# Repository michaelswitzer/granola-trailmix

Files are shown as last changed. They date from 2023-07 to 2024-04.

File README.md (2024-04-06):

# TrailMix by Granola Arcade

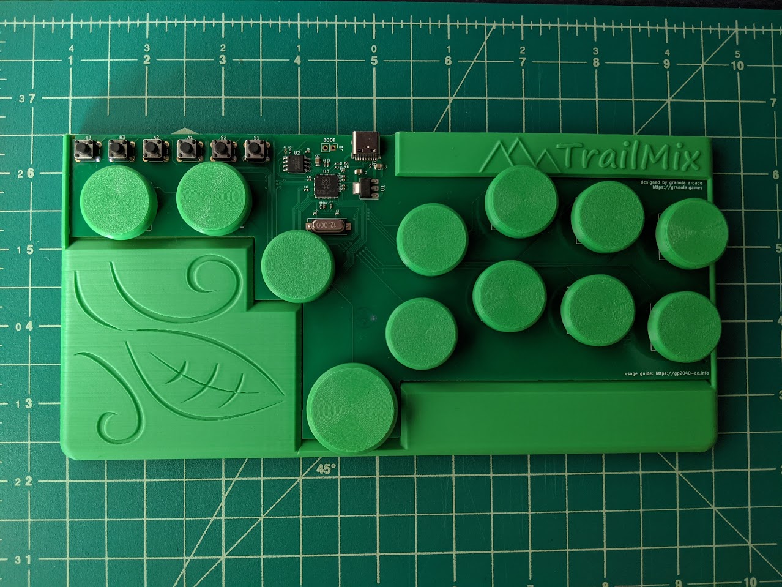
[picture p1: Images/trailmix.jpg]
TrailMix fightstick


The TrailMix is a button box style arcade controller by Granola Arcade. It is designed to provide the minimum cost professional grade arcade stick available. The design of the TrailMix is simplified down to the core, without any of the bells and whistles that add cost and complexity. Win your local without breaking the bank!

You can no longer buy the TrailMix from Granola but you can buy our current controllers at https://granola.games

## Should you make a TrailMix?
Building your own TrailMix will definitely be more expensive than buying one directly from Granola Arcade, and it isn't as fun to put together as some of the other DIY options out there. Nevertheless, if you decide to press on, the files in this repository should have everything you need.

## How to build
To build your own TrailMix, import the PCB designs and bill of materials using KiCAD. I provided a list of parts that use JLCPCB's part assembly services, since that is the company I use to manufacture the PCB. You can use these files as a starting point for building your own PCB.

The STL file for the case is optimized for FDM 3D printers. I recommend PLA with at least 15% infill but you can use any material you wish. The case is designed to be printed on the thin edge on the top side, which can cause some stability challenges when printing. **This orientation is better suited to printers that do not move their print bed side to side, and can be tricky to print on Prusa/Ender/etc. printers.** If you use a "bed slinger" printer such as these, make sure you have good bed adhesion.

You will also need to source your own key switches and keycaps. The TrailMix uses Kailh low-profile "Choc v1" keyboard switches.

## Firmware
The TrailMix is designed to use the <a rel="GP2040-CE firmware" href="https://github.com/OpenStickCommunity/GP2040-CE">GP2040-CE firmware</a>. You want the .uf2 file for the Raspberry Pi Pico as it has the same pinouts as the TrailMix. If you wish to use different firmware, you can view the schematic files to understand the layout of the board. If you bridge the Boot and GND pins (marked "BOOT" on the PCB) as you plug in the USB cord, you can upload new firmware in .uf2 format.

## Credits
The TrailMix was designed by Michael Switzer. The GP2040-CE firmware is maintained by <a href="https://github.com/OpenStickCommunity">OpenStickCommunity</a>. This project was inspired by the <a href="https://github.com/jfedor2/flatbox">Flatbox</a>.

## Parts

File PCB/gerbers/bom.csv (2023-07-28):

Comment | Designator | Footprint | LCSC Part Number
10uF | C1,C2 | Capacitor_SMD:C_0805_2012Metric | C83061
27p | C3,C4 | Capacitor_SMD:C_0402_1005Metric | C147436
100nF | C5,C6,C7,C9,C11,C12,C13,C14,C15,C16 | Capacitor_SMD:C_0402_1005Metric | C115671
1uF | C8,C10 | Capacitor_SMD:C_0402_1005Metric | C5137485
10uF | C17 | Capacitor_SMD:C_0805_2012Metric | C83061
HRO-TYPE-C-31-M-12 | USB1 | Type-C:HRO-TYPE-C-31-M-12-Assembly | C165948
1k | R1,R5 | Capacitor_SMD:C_0402_1005Metric | C105637
5.1k | R6,R7 | Resistor_SMD:R_0402_1005Metric | C25905
27 ohm | R3,R4 | Capacitor_SMD:C_0402_1005Metric | C2909343
6mm_Button | SW1,SW2,SW3,SW4,SW5,SW6 | Button_Switch_THT:SW_PUSH_6mm | C782807
AMS1117 | U1 | Package_TO_SOT_SMD:SOT-223-3_TabPin2 | C5250992
W25Q128JVS | U2 | Package_SO:SOIC-8_5.23x5.23mm_P1.27mm | C97521
RP2040 | U3 | RP2040_minimal:RP2040-QFN-56 | C2040
Crystal_GND24 | Y1 | Crystal:Crystal_SMD_3225-4Pin_3.2x2.5mm | C9002

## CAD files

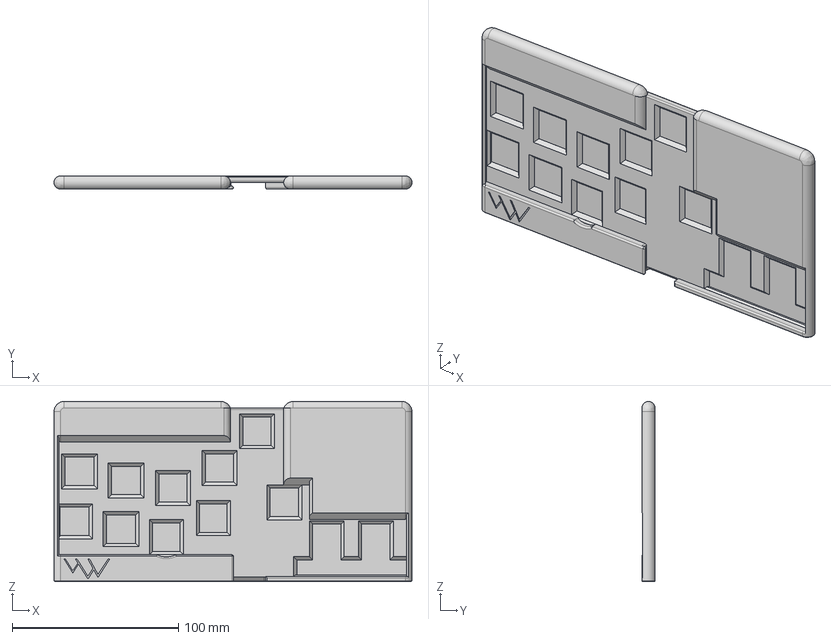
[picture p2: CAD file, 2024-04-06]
Case/trailmix-blank-case.step
215.1 x 8.00 x 108.2 mm

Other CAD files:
Case/trailmix-leaf-case.step

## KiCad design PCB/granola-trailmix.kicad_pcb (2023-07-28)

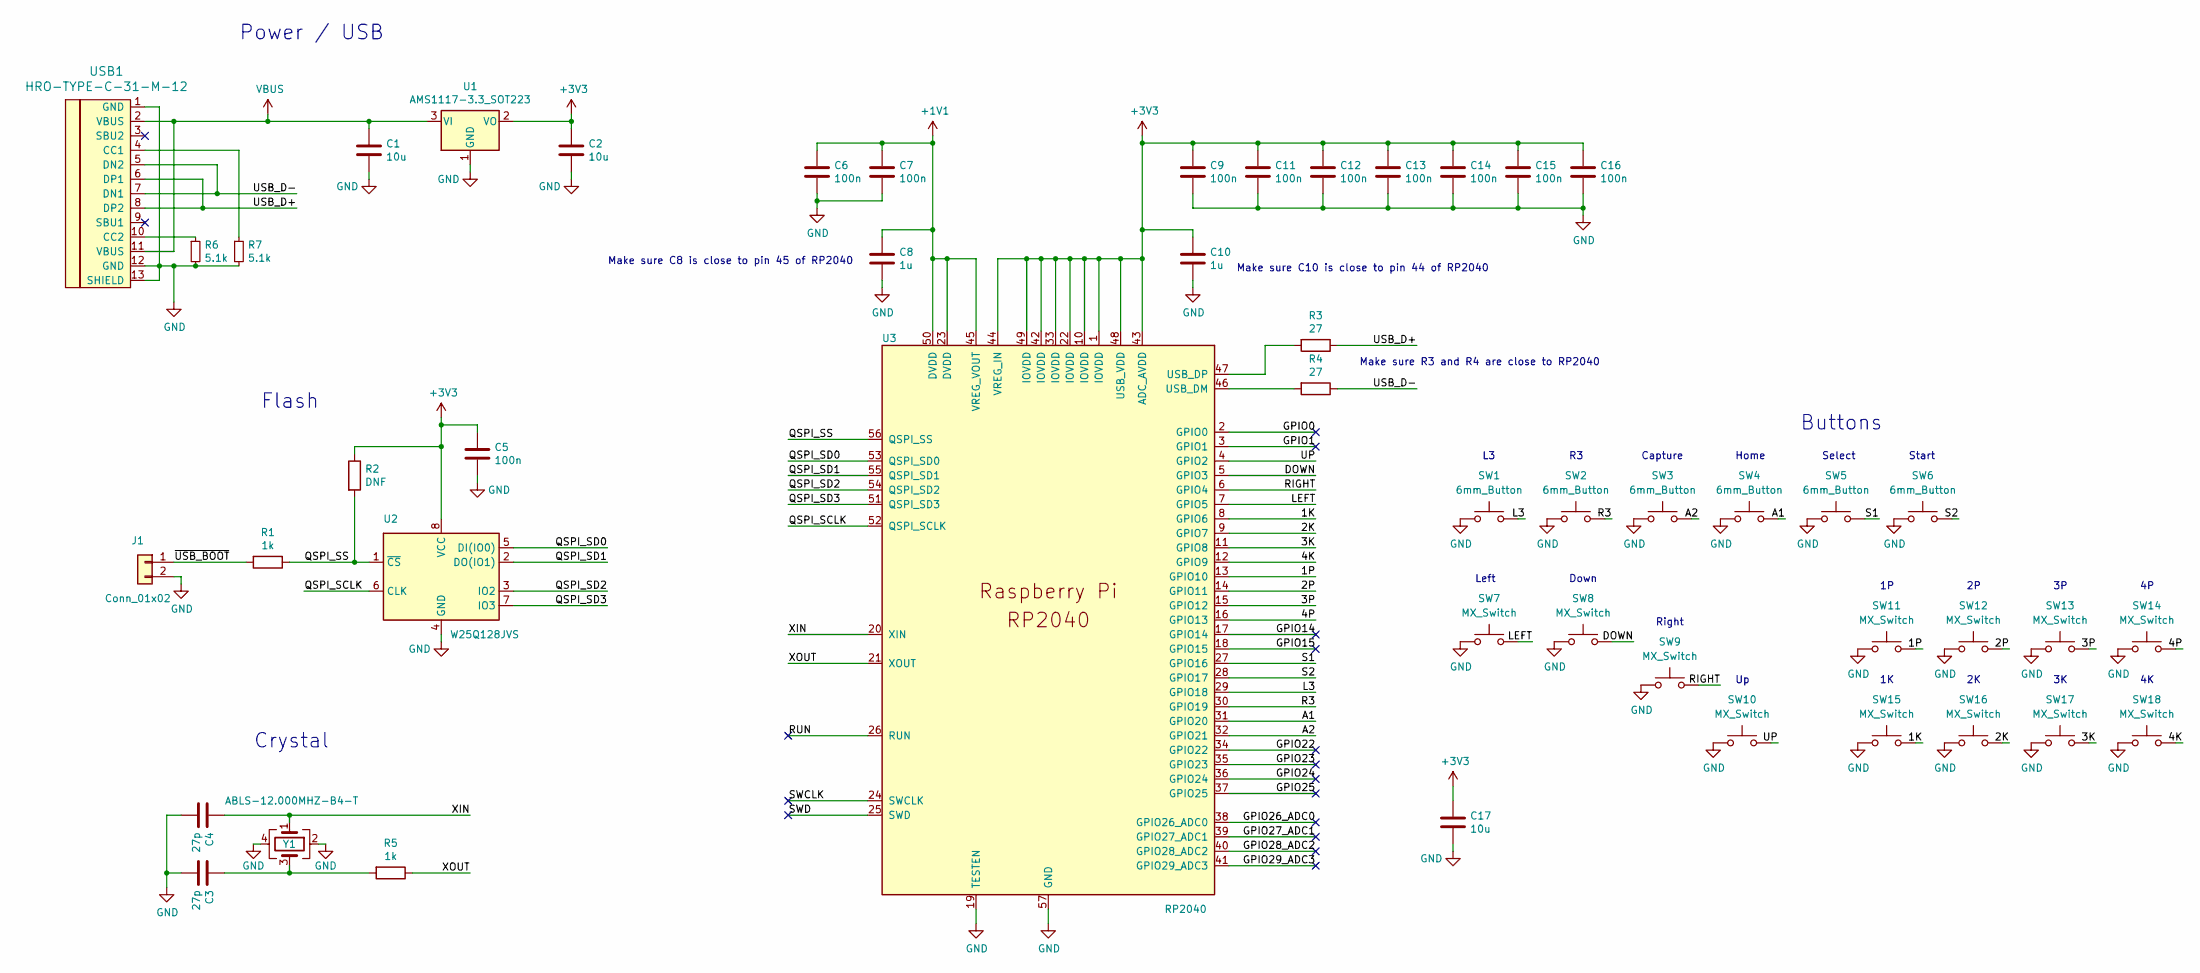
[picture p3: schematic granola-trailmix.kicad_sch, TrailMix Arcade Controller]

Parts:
C1, C2, C17: 10u; C_0805_2012Metric; LCSC C83061
C3, C4: 27p; C_0402_1005Metric; LCSC C147436
C5, C6, C7, C9, C11, C12, C13, C14, C15, C16: 100n; C_0402_1005Metric; LCSC C115671
C8, C10: 1u; C_0402_1005Metric; LCSC C5137485
J1: Conn_01x02; PinHeader_1x02_P2.54mm_Vertical
R1, R5: 1k; C_0402_1005Metric; LCSC C105637
R2: DNF; C_0402_1005Metric
R3, R4: 27; C_0402_1005Metric; LCSC C2909343
R6, R7: 5.1k; R_0402_1005Metric; LCSC C25905
SW1, SW2, SW3, SW4, SW5, SW6: 6mm_Button; SW_PUSH_6mm; LCSC C782807
SW7, SW8, SW9, SW10, SW11, SW12, SW13, SW14, SW15, SW16, SW17, SW18: MX_Switch; SW_Kailh_Choc_V1_1.00u
U1: AMS1117-3.3_SOT223; SOT-223-3_TabPin2; LCSC C5250992
U2: W25Q128JVS; SOIC-8_5.23x5.23mm_P1.27mm; LCSC C97521
U3: RP2040; RP2040-QFN-56; LCSC C2040
USB1: HRO-TYPE-C-31-M-12; HRO-TYPE-C-31-M-12-Assembly; LCSC C165948
Y1: ABLS-12.000MHZ-B4-T; Crystal_SMD_3225-4Pin_3.2x2.5mm; LCSC C9002

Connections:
+1V1: C6.1, C7.1, C8.1, U3.23 (DVDD), U3.45 (VREG_VOUT), U3.50 (DVDD)
+3V3: C2.1, C5.1, C9.1, C10.1, C11.1, C12.1, C13.1, C14.1, C15.1, C16.1, C17.1, R2.1, U1.2 (VO), U2.8 (VCC), U3.1 (IOVDD), U3.10 (IOVDD), U3.22 (IOVDD), U3.33 (IOVDD), U3.42 (IOVDD), U3.43 (ADC_AVDD), U3.44 (VREG_IN), U3.48 (USB_VDD), U3.49 (IOVDD)
/1K: SW15.1 (A), U3.8 (GPIO6)
/1P: SW11.1 (A), U3.13 (GPIO10)
/2K: SW16.1 (A), U3.9 (GPIO7)
/2P: SW12.1 (A), U3.14 (GPIO11)
/3K: SW17.1 (A), U3.11 (GPIO8)
/3P: SW13.1 (A), U3.15 (GPIO12)
/4K: SW18.1 (A), U3.12 (GPIO9)
/4P: SW14.1 (A), U3.16 (GPIO13)
/A1: SW4.1 (A), U3.31 (GPIO20)
/A2: SW3.1 (A), U3.32 (GPIO21)
/DOWN: SW8.1 (A), U3.5 (GPIO3)
/GPIO0: U3.2 (GPIO0)
/GPIO1: U3.3 (GPIO1)
/GPIO14: U3.17 (GPIO14)
/GPIO15: U3.18 (GPIO15)
/GPIO22: U3.34 (GPIO22)
/GPIO23: U3.35 (GPIO23)
/GPIO24: U3.36 (GPIO24)
/GPIO25: U3.37 (GPIO25)
/GPIO26_ADC0: U3.38 (GPIO26_ADC0)
/GPIO27_ADC1: U3.39 (GPIO27_ADC1)
/GPIO28_ADC2: U3.40 (GPIO28_ADC2)
/GPIO29_ADC3: U3.41 (GPIO29_ADC3)
/L3: SW1.1 (A), U3.29 (GPIO18)
/LEFT: SW7.1 (A), U3.7 (GPIO5)
/QSPI_SCLK: U2.6 (CLK), U3.52 (QSPI_SCLK)
/QSPI_SD0: U2.5 (DI(IO0)), U3.53 (QSPI_SD0)
/QSPI_SD1: U2.2 (DO(IO1)), U3.55 (QSPI_SD1)
/QSPI_SD2: U2.3 (IO2), U3.54 (QSPI_SD2)
/QSPI_SD3: U2.7 (IO3), U3.51 (QSPI_SD3)
/QSPI_SS: R1.1, R2.2, U2.1 (~CS), U3.56 (QSPI_SS)
/R3: SW2.1 (A), U3.30 (GPIO19)
/RIGHT: SW9.1 (A), U3.6 (GPIO4)
/RUN: U3.26 (RUN)
/S1: SW5.1 (A), U3.27 (GPIO16)
/S2: SW6.1 (A), U3.28 (GPIO17)
/SWCLK: U3.24 (SWCLK)
/SWD: U3.25 (SWD)
/UP: SW10.1 (A), U3.4 (GPIO2)
/USB_D+: R3.1, USB1.6 (DP1), USB1.8 (DP2)
/USB_D-: R4.1, USB1.5 (DN2), USB1.7 (DN1)
/XIN: C4.1, U3.20 (XIN), Y1.1
/XOUT: R5.1, U3.21 (XOUT)
/~USB_BOOT: J1.1, R1.2
GND: C1.2, C2.2, C3.2, C4.2, C5.2, C6.2, C7.2, C8.2, C9.2, C10.2, C11.2, C12.2, C13.2, C14.2, C15.2, C16.2, C17.2, J1.2, R6.2, R7.2, SW1.2 (B), SW2.2 (B), SW3.2 (B), SW4.2 (B), SW5.2 (B), SW6.2 (B), SW7.2 (B), SW8.2 (B), SW9.2 (B), SW10.2 (B), SW11.2 (B), SW12.2 (B), SW13.2 (B), SW14.2 (B), SW15.2 (B), SW16.2 (B), SW17.2 (B), SW18.2 (B), U1.1 (GND), U2.4 (GND), U3.19 (TESTEN), U3.57 (GND), USB1.1 (GND), USB1.12 (GND), USB1.13 (SHIELD), Y1.2, Y1.4
unnamed: C3.1, R5.2, Y1.3
unnamed: R3.2, U3.47 (USB_DP)
unnamed: R4.2, U3.46 (USB_DM)
unnamed: R6.1, USB1.10 (CC2)
unnamed: R7.1, USB1.4 (CC1)
VBUS: C1.1, U1.3 (VI), USB1.2 (VBUS), USB1.11 (VBUS)

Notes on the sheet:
Right
Start
Capture
Down
Left
Make sure R3 and R4 are close to RP2040
Crystal
Make sure C10 is close to pin 44 of RP2040
Flash
Power / USB
Select
Buttons
Home
Make sure C8 is close to pin 45 of RP2040

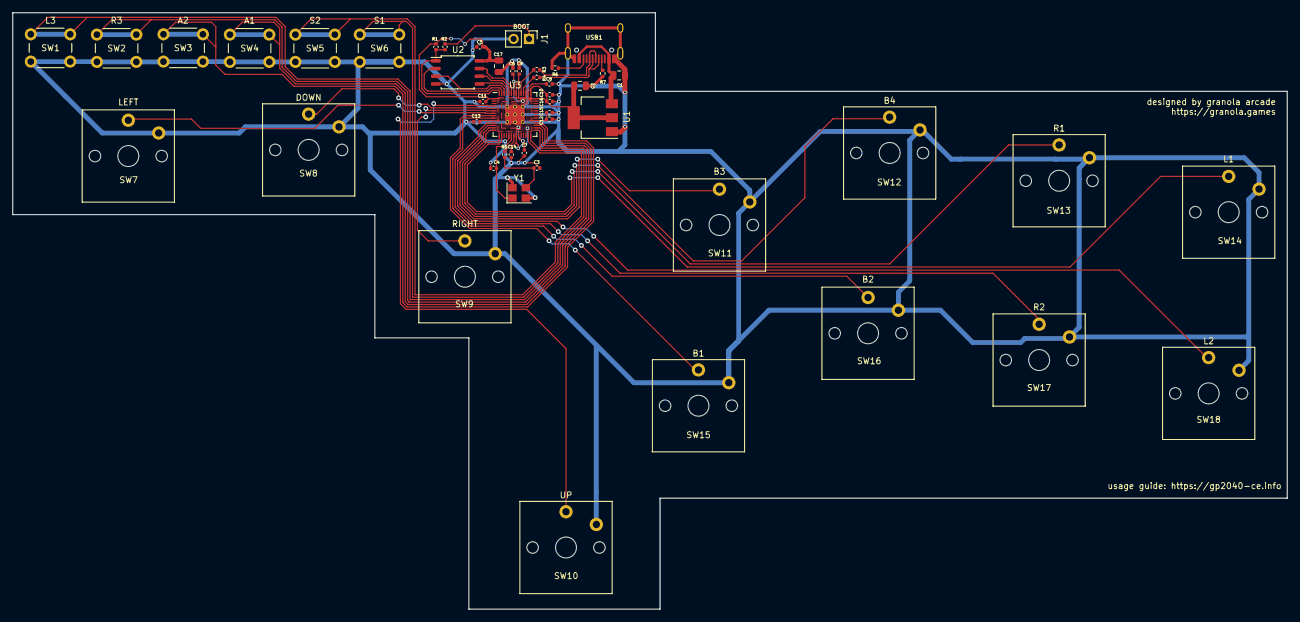
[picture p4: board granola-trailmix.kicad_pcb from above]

Board: 2 copper layers, 210.1 x 98.3 mm, 48 parts (0 on the bottom side), 38 nets.

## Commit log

2023-05-26 Design files
    [Trailmix-case.stl, granola-trailmix.kicad_pcb, granola-trailmix.kicad_sch]
2023-05-26 bill of materials
    [bom.csv]
2023-06-03 gerber files
    [bom.csv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]
2023-07-04 vertical print case, minor pcb changes
    [Trailmix-case.stl, granola-trailmix.kicad_pcb]
2023-07-04 case print orientation
    [Trailmix-case.stl]
2023-07-07 removed easter egg as it doesn't show up on an actually nice printer
    [Trailmix-case.stl]
2023-07-11 small case dimension adjustment for more reliable fit
    [Trailmix-case.stl]
2023-07-11 moved logo to avoid impact with buttons
    [Trailmix-case.stl]
2023-07-12 Just a bit more adjustments
    [Trailmix-case.stl]
2023-07-13 Slightly widen case to accomodate PCB tolerances
    [Trailmix-case.stl]
2023-07-20 remove chamfer to make warping less likely
    [Trailmix-case.stl]
2023-07-28 Updated PCB to new crystal. Added version of TrailMix case that has no front design.
    [Trailmix-case-no-front-design.stl, bom.csv, granola-trailmix.kicad_pcb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]
2023-08-02 added non slip pads for case
    [Trailmix-case-no-front-design.stl, Trailmix-case.stl]
2023-09-15 case model switch to step files from stl
    [Trailmix-case-no-front-design-no-logo.step, Trailmix-case-no-front-design.step, Trailmix-case-no-front-design.stl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]
2024-04-06 Updated case design
    [trailmix-blank-case.step, trailmix-leaf-case.step]
